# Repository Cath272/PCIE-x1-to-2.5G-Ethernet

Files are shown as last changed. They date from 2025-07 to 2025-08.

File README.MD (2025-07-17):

# PCIE x1 to 2.5Gb Ethernet
 Pcie to 2.5GbE  using RTL8125

 ## RTL8125BG 

  - Integrated 10/100/1000M/2.5G transceiver

  - 

 ## TPS

 - 5V to 0.95V DC-DC (1A)

 ## LX82405SP
 -2.5GbE Magnetics 
## PCB 
This board uses a 4 layer stackup with a  1.6mm thickness:

- POWER/SIGNAL

- GND
  
- GND
  
- POWER/SIGNAL

High Speed diferential lines need a refrence ground plane so internal planes are ground referance planes for the High speed pcie lanes

TBD: photos and schematic
### Schematic:
Schematic
## PCB Screenshots

usb3ethfront
usb3ethback
usb3ethfront3d
usb3ethback3d

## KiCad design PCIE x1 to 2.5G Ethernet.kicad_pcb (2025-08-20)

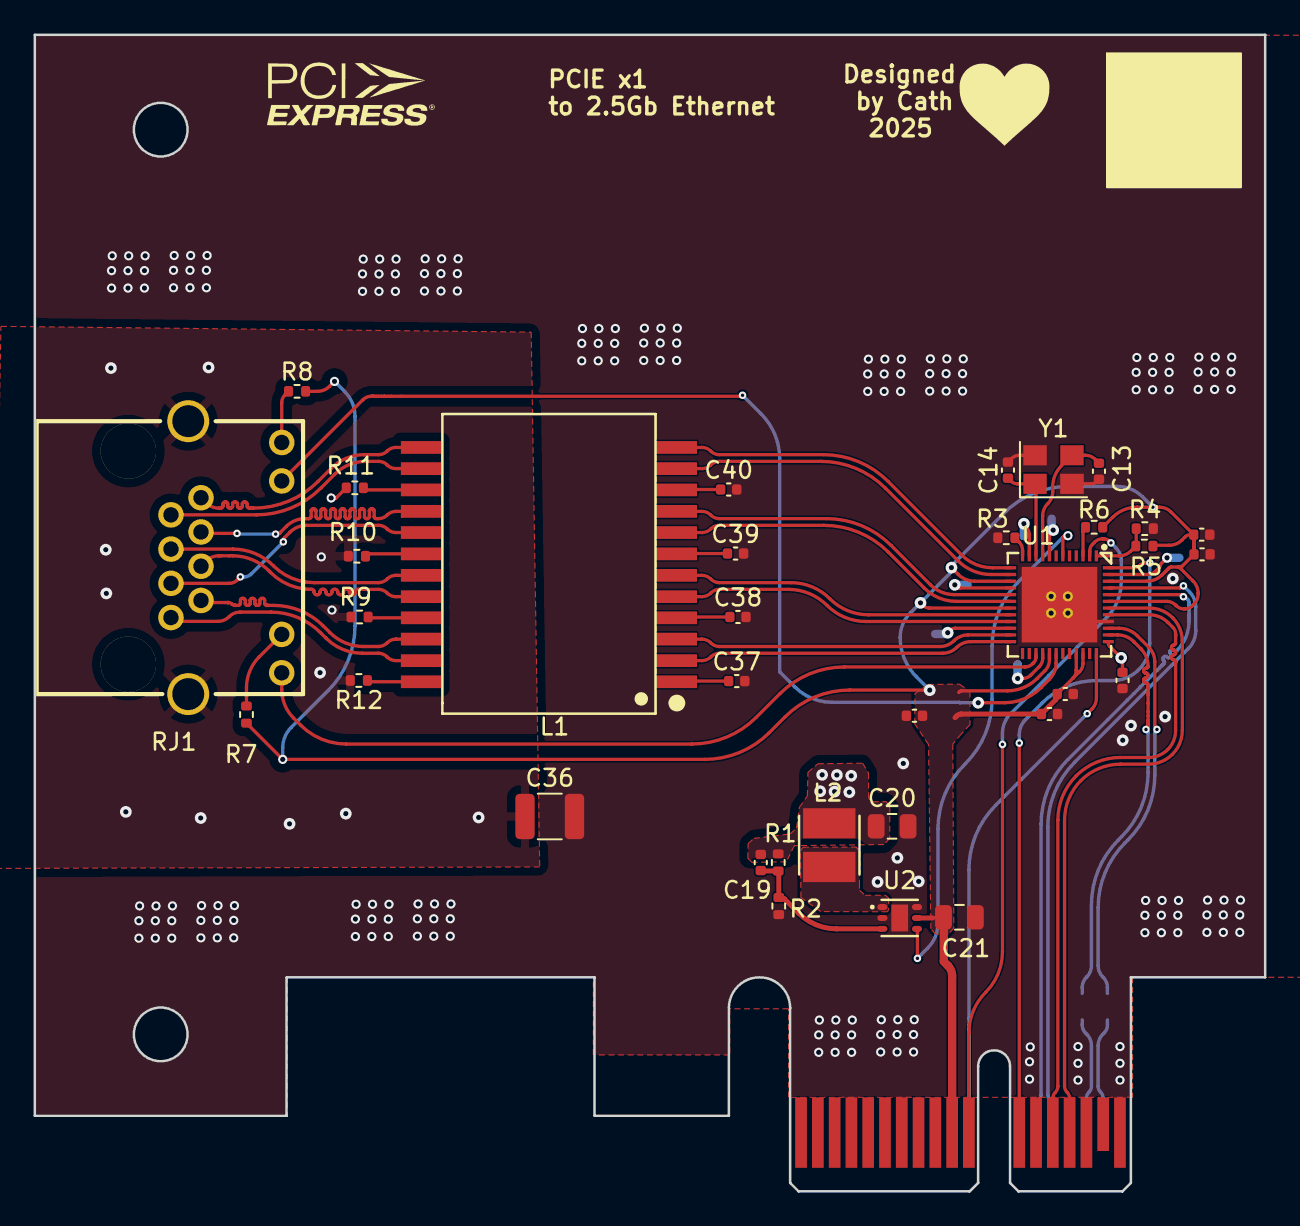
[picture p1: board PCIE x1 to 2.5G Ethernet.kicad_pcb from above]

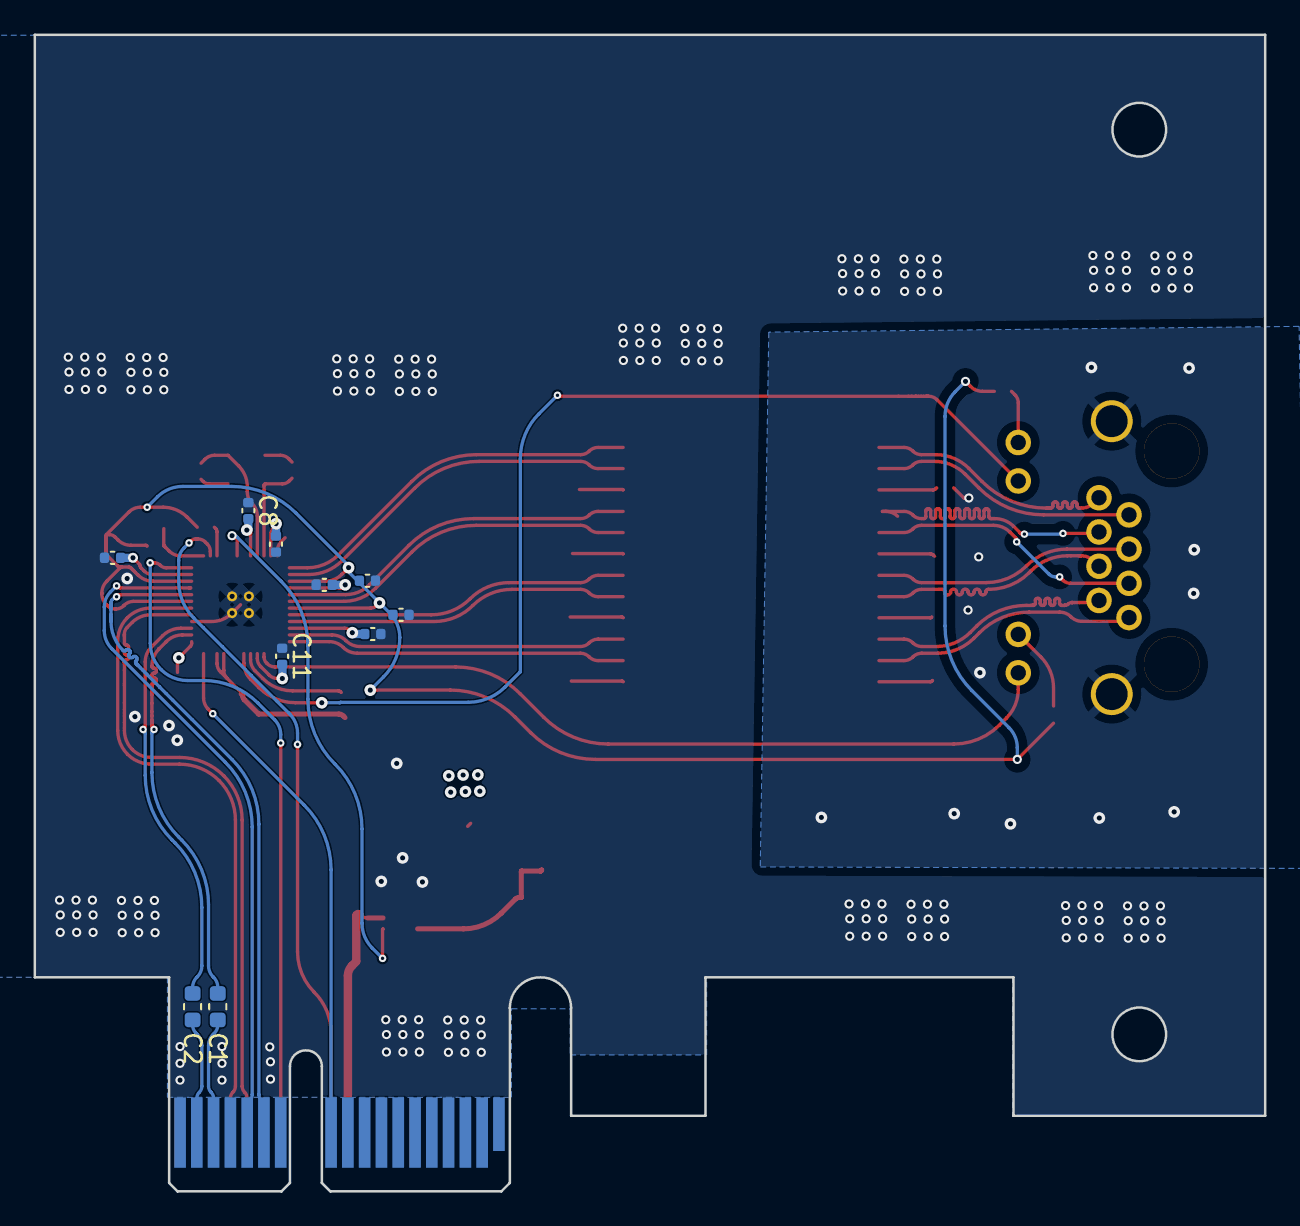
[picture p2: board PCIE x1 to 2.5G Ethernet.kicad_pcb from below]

Board: 4 copper layers, 73.3 x 68.9 mm, 46 parts (10 on the bottom side), 51 nets.

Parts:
C1, C2: 100n; C_0603_1608Metric
C3, C4, C5, C6, C7, C8, C9, C10, C11, C12, C15, C16, C17, C18, C37, C38, C39, C40: 100nF; C_0402_1005Metric
C13, C14: 18pF; C_0402_1005Metric
C19: 22pF; C_0402_1005Metric
C20, C21: 10uF; C_0805_2012Metric
C36: 1nF 2kV; C_1210_3225Metric
J1: PCIexpress_bracket; PCIexpress_bracket_low
J2: PCIexpress_x1
L1: HY602401; XFMR-SMD_HY602401
L2: 2.2uH; IND-SMD_L3.5-W3.0
R1: 160k; R_0402_1005Metric
R2: 280k; R_0402_1005Metric
R3: 2.49k; R_0402_1005Metric
R4, R6: 15K; R_0402_1005Metric
R5: 1K; R_0402_1005Metric
R7, R8: 220R; R_0402_1005Metric
R9, R10, R11, R12: 75R; R_0402_1005Metric
RJ1: R-RJ45R08P-C000; RJ45-TH_R-RJ45R08P-C000
U1: RTL8125BG-CG; TQFN-48_L6.0-W6.0-P0.40-BL-EP4.5
U2: TPS62590DRVT; WSON-6_L2.0-W2.0-P0.65-TL-EP
Y1: 25Mhz; Crystal_SMD_3225-4Pin_3.2x2.5mm

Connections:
+0.95V: C3.2, C6.2, C7.2, C8.2, C10.2, C11.2, C15.2, C19.1, C20.1, L2.1, R1.1, U1.8 (DVDD09), U1.11 (AVDD09), U1.16 (AVDD09), U1.22 (AVDD09), U1.28 (DVDD09), U1.37 (EVDD09), U1.47 (DVDD09)
+3.3VA: C4.2, C5.2, C9.2, C12.2, C16.2, C17.2, C18.2, C21.1, J2.B10 (+3.3V_aux), R5.1, R6.1, R7.1, R8.2, U1.15 (AVDD33), U1.19 (AVDD33), U1.29 (DVDD33), U1.33 (AVDD33), U1.34 (AVDD33_XTAL), U1.43 (EVDD33), U1.46 (DVDD33), U2.5 (VIN)
/Connectors/PCIexpress_connector/_PER0_N: C2.1, J2.A17 (PERn0)
/Connectors/PCIexpress_connector/_PER0_P: C1.2, J2.A16 (PERp0)
CLK_REQ: J2.B12 (CLK_REQ), U1.48 (CLKREQB)
ETH_GND: C36.1, R9.2, R10.2, R11.2, R12.2, RJ1.13 (S), RJ1.14 (S)
GND: C3.1, C4.1, C5.1, C6.1, C7.1, C8.1, C9.1, C10.1, C11.1, C12.1, C13.1, C14.2, C15.1, C16.1, C17.1, C18.1, C20.2, C21.2, C36.2, C37.2, C38.2, C39.2, C40.2, J2.A4 (GND), J2.A12 (GND), J2.A15 (GND), J2.A18 (GND), J2.B4 (GND), J2.B7 (GND), J2.B13 (GND), J2.B16 (GND), J2.B18 (GND), R2.2, R3.1, R4.1, U1.40 (GND), U1.49 (GND), U2.2 (MODE), U2.6 (GND), U2.7 (EP), Y1.2, Y1.4
LED0: RJ1.10 (L-), U1.30 (LED0/EEDI/SPISI/SDA)
LED1: RJ1.12 (R-), U1.27 (LED1/EESK/SPISC)
MD1+: L1.13 (MX4-), RJ1.8
MD1-: L1.14 (MX4+), RJ1.7
MD2+: L1.16 (MX3-), RJ1.6
MD2-: L1.17 (MX3+), RJ1.3
MD3+: L1.19 (MX2-), RJ1.5
MD3-: L1.20 (MX2+), RJ1.4
MD4+: L1.22 (MX1-), RJ1.2
MD4-: L1.23 (MX1+), RJ1.1
MDIN0: L1.11 (TD4+), U1.14 (MDIN0)
MDIN1: L1.8 (TD3+), U1.18 (MDIN1)
MDIN2: L1.5 (TD2+), U1.21 (MDIN2)
MDIN3: L1.2 (TD1+), U1.24 (MDIN3)
MDIP0: L1.12 (TD4-), U1.13 (MDIP0)
MDIP1: L1.9 (TD3-), U1.17 (MDIP1)
MDIP2: L1.6 (TD2-), U1.20 (MDIP2)
MDIP3: L1.3 (TD1-), U1.23 (MDIP3)
unnamed: L1.24 (MCT1), R12.1
unnamed: L1.21 (MCT2), R9.1
unnamed: L1.18 (MCT3), R10.1
unnamed: L1.15 (MCT4), R11.1
unnamed: C37.1, L1.1 (TCT1)
unnamed: C38.1, L1.4 (TCT2)
unnamed: C39.1, L1.7 (TCT3)
unnamed: C40.1, L1.10 (TCT4)
unnamed: R8.1, RJ1.9 (L+)
unnamed: R7.2, RJ1.11 (R+)
unnamed: C14.1, U1.10 (CKXTAL1), Y1.1
unnamed: C13.2, U1.9 (CKXTAL2), Y1.3
unnamed: R6.2, U1.3 (GPI)
unnamed: R4.2, R5.2, U1.1 (ISOLATEB)
unnamed: R3.2, U1.12 (RSET)
unnamed: C19.2, R1.2, R2.1, U2.3 (FB)
unnamed: L2.2, U2.1 (SW)
PER0+: C1.1, U1.38 (HSOP)
PER0-: C2.2, U1.39 (HSON)
PERST: J2.A11 (~PERST), U1.36 (PERSTB)
PET0+: J2.B14 (PETp0), U1.41 (HSIP)
PET0-: J2.B15 (PETn0), U1.42 (HSIN)
REFCLK+: J2.A13 (REFCLK+), U1.44 (REFCLK_P)
REFCLK-: J2.A14 (REFCLK-), U1.45 (REFCLK_N)
REG_EN: U1.6 (POW_EXT_SWR), U2.4 (EN)
WAKE: J2.B11 (~WAKE), U1.2 (LANWAKEB)
